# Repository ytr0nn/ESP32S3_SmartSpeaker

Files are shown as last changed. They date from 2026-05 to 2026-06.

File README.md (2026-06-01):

# ESP32S3_SmartSpeaker

An open-source, fully functional AI-powered smart speaker built around the **ESP32S3** microcontroller. The project features local wake-word detection, seamless integration with cloud-based AI models (OpenAI & Google Gemini), and dynamic visual feedback using a round LCD display and an addressable LED ring.

## Features

* **Local Wake Word Detection:** Uses the ESPSR framework to recognize the wake word locally, ensuring low latency.
* **Cloud AI Pipeline:** * **STT:** OpenAI Whisper API.
  * **LLM :** Google Gemini 3.5 Flash API for fast and smart responses.
  * **TTS :** OpenAI TTS API.
* **High-Quality Audio:** Employs an I2S digital MEMS microphone for clear voice capture and an I2S DAC for crisp audio playback.
* **Rich User Interface:** * A GC9A01 round display powered by **LVGL** showing device states and real-time clock.
  * A WS2812B addressable LED ring providing smooth, color-coded animations.
* **RTOS Architecture:** Built on **FreeRTOS** using the native **ESP-IDF**.
* **Custom Enclosure:** Designed specifically for 3D printing to optimize acoustics and component mounting.

## 🛠️ Hardware Requirements

* **Development Board:** ESP32S3 DevKit (Must have **8MB PSRAM** for audio buffering and TLS handshake).
* **Microphone:** ICS43434.
* **DAC / Amplifier:** PCM5102 + D class compact Audio Amplifier.
* **Display:** GC9A01 240x240 Round LCD .
* **LED Ring:** WS2812B (32 LEDs).
* **Audio Switch:** CD4053BE Analog Multiplexer (for switching between ESP32 and Bluetooth audio sources).
* **Misc:** Capacitive touch buttons, 3D printed enclosure.

## 💻 Software & APIs

* **Framework:** ESP-IDF v5.3+.
* **Libraries:** LVGL , ESP-SR , cJSON.
* **API Keys Required:**
  * OpenAI API Key Whisper & TTS
  * Google Gemini API Key

## ⚙️ Architecture & Flow

1. **Idle:** The device syncs time via SNTP. The display shows a blue pulsating orb and the LED ring "breathes".
2. **Wake Word:** The `ICS43434` mic feeds data to the `ESPSR` engine. Upon detecting wake word, the UI turns yellow.
3. **Recording:** Voice is recorded into the ESP32's PSRAM. VAD automatically stops recording when silence is detected.
4. **Processing (White UI):** The audio is encapsulated with a WAV header and sent to **OpenAI Whisper**. The recognized text is forwarded to **LLM**.
5. **Playback (Green UI/Rainbow LED):** The text response is sent to **OpenAI TTS**, and the resulting audio stream is played back via the `PCM5102` DAC.

## 🚀 Installation & Setup
```bash
1. Clone the Repository

git clone [https://github.com/ytr0nn/ESP32S3_SmartSpeaker.git](https://github.com/ytr0nn/ESP32S3_SmartSpeaker.git)
cd ESP32S3_SmartSpeaker

2. Configure API Keys and Wi-Fi

Open main/network_api.h and main/ai_agent.h or your config files and insert your credentials

3. ESP-IDF Menuconfig (CRITICAL SETTINGS)

Because AI APIs require large SSL certificates, you must configure mbedTLS to use PSRAM. Run:
Bash

idf.py menuconfig

Apply the following settings:

    ESP-TLS: Enable Use global CA store and Use PSRAM for SSL session.

    mbedTLS: Set Memory allocation strategy to Allocate SSL/TLS memory into PSRAM.

    ESP System Settings: Enable Allow external memory as a heap pool.

    Component config -> ESP Speech Recognition: Ensure your partition table matches the model size.

4. Build and Flash
Bash

idf.py build
idf.py -p (YOUR PORT) flash monitor

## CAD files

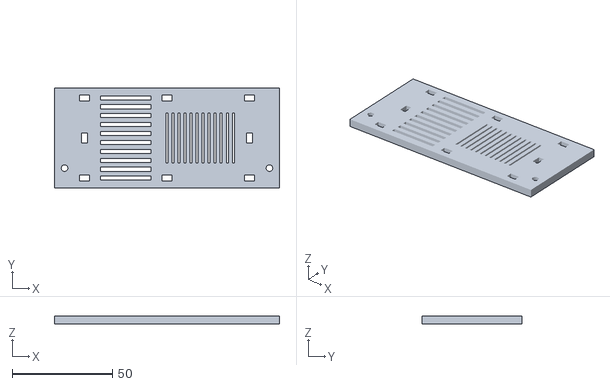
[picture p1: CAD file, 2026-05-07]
ESP32_S3_Smart_Speaker/3D files/Board Holder.stl
112.0 x 50.0 x 4.00

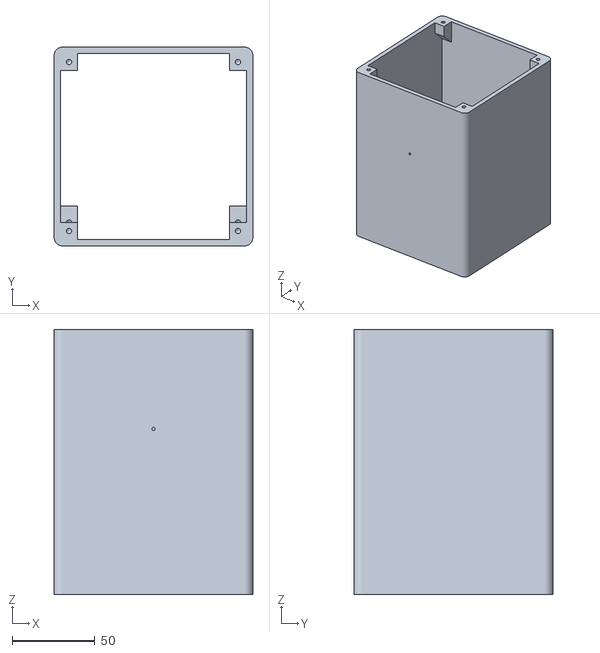
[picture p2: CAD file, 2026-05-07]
ESP32_S3_Smart_Speaker/3D files/CASE.stl
120.0 x 120.0 x 160.0

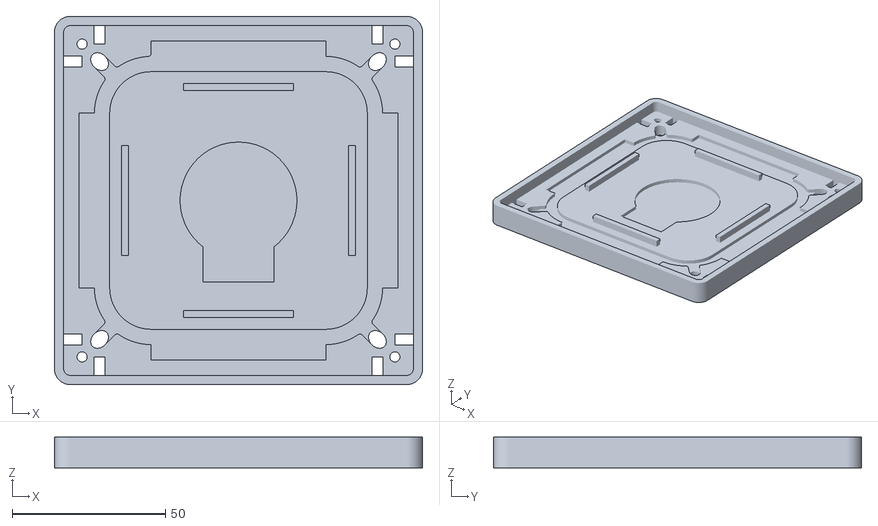
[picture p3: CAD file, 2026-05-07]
ESP32_S3_Smart_Speaker/3D files/Display Module.stl
120.0 x 120.0 x 10.0

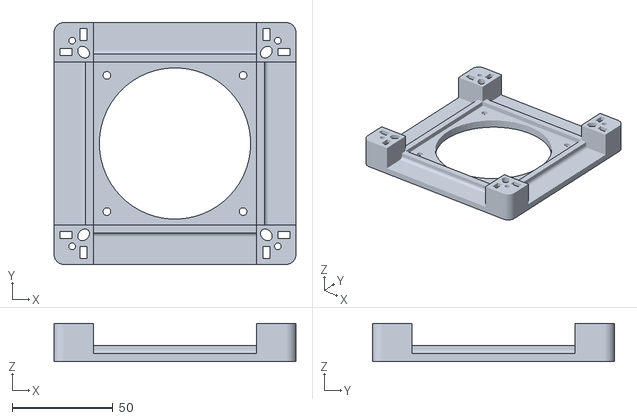
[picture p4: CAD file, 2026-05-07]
ESP32_S3_Smart_Speaker/3D files/Middle Frame.stl
120.0 x 120.0 x 19.0

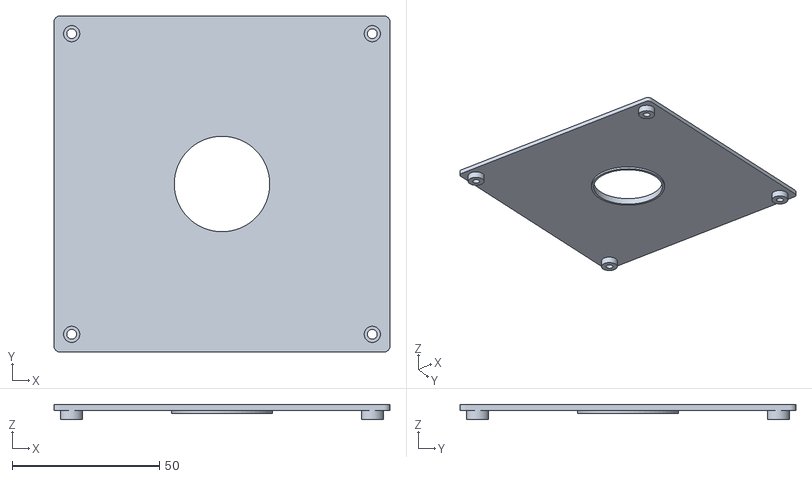
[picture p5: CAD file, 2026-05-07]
ESP32_S3_Smart_Speaker/3D files/Top lid.stl
114.0 x 114.0 x 5.00

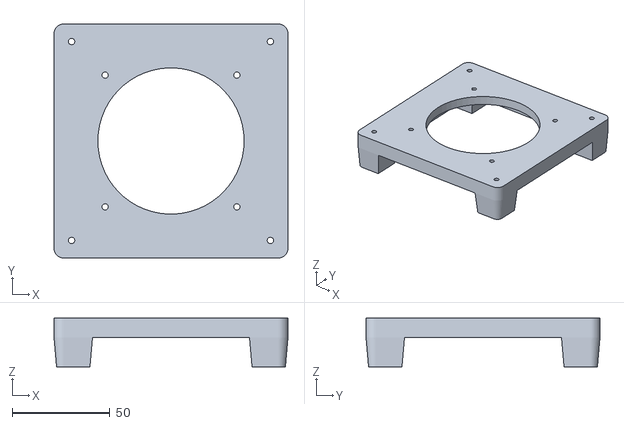
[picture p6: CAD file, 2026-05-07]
ESP32_S3_Smart_Speaker/3D files/LEGS.stl
120.0 x 120.0 x 25.0

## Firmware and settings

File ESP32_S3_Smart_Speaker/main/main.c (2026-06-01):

#include <stdio.h>
#include "esp_log.h"
#include "nvs_flash.h"
#include "esp_event.h"
#include "sys_manager.h"

static const char *TAG = "MAIN";

void app_main(void)
{
    ESP_LOGI(TAG, "Starting Smart AI Speaker Initialization YURII OSYPENKO");
    ESP_LOGI(TAG, "Free heap: %" PRIu32 " bytes", esp_get_free_heap_size());

    // 1. NVS 
    // 
    esp_err_t ret = nvs_flash_init();
    if (ret == ESP_ERR_NVS_NO_FREE_PAGES || ret == ESP_ERR_NVS_NEW_VERSION_FOUND) {
        ESP_LOGW(TAG, "NVS flash error");
        ESP_ERROR_CHECK(nvs_flash_erase());
        ret = nvs_flash_init();
    }
    ESP_ERROR_CHECK(ret);

    // 2. (ESP Event Loop)
    // 
    ESP_ERROR_CHECK(esp_event_loop_create_default());

    // 3.maneger
    // 
    // 
    sys_manager_init();

    ESP_LOGI(TAG, "Initialization complete. System Manager is running.");
    
}

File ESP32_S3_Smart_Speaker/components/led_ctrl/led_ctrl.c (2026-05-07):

#include "led_ctrl.h"
#include "esp_log.h"
#include "esp_err.h"
#include "freertos/FreeRTOS.h"
#include "freertos/task.h"
#include "led_strip.h"
#include "sys_manager.h"
#include <math.h>

static const char *TAG = "LED_CTRL";

// --- Hardware Configuration ---
#define LED_STRIP_BLINK_GPIO  48
#define LED_STRIP_LED_NUMBERS 32
#define LED_FRAME_RATE_MS     30  // ~33 FPS for smooth animations

static led_strip_handle_t led_strip;
static sys_state_t current_state = STATE_IDLE;

// ==============================================================================
// System Event Handler
// ==============================================================================
static void sys_event_handler(void* arg, esp_event_base_t event_base, int32_t event_id, void* event_data) {
    if (event_base == SYS_EVENT_BASE && event_id == SYS_EVENT_STATE_CHANGED) {
        if (event_data) {
            sys_state_t new_state = *(sys_state_t*)event_data;
            if (current_state != new_state) {
                ESP_LOGI(TAG, "LED state transitioning to: %d", new_state);
                current_state = new_state;
            }
        }
    }
}

// ==============================================================================
// Animation Patterns
// ==============================================================================

// Helper to convert HSV to RGB for smoother color transitions
static void hsv2rgb(uint32_t h, uint32_t s, uint32_t v, uint32_t *r, uint32_t *g, uint32_t *b) {
    h %= 360; 
    uint32_t rgb_max = v * 2.55f;
    uint32_t rgb_min = rgb_max * (100 - s) / 100.0f;
    uint32_t i = h / 60;
    uint32_t diff = h % 60;
    uint32_t rgb_adj = (rgb_max - rgb_min) * diff / 60;

    switch (i) {
        case 0: *r = rgb_max; *g = rgb_min + rgb_adj; *b = rgb_min; break;
        case 1: *r = rgb_max - rgb_adj; *g = rgb_max; *b = rgb_min; break;
        case 2: *r = rgb_min; *g = rgb_max; *b = rgb_min + rgb_adj; break;
        case 3: *r = rgb_min; *g = rgb_max - rgb_adj; *b = rgb_max; break;
        case 4: *r = rgb_min + rgb_adj; *g = rgb_min; *b = rgb_max; break;
        default: *r = rgb_max; *g = rgb_min; *b = rgb_max - rgb_adj; break;
    }
}

static void led_animation_task(void *pvParameters) {
    ESP_LOGI(TAG, "LED Animation Task started on Core %d", xPortGetCoreID());
    
    uint32_t tick = 0;
    uint32_t r, g, b;

    while (1) {
        led_strip_clear(led_strip);

        switch (current_state) {
            case STATE_WIFI_SETUP: {
    // slow blue for Wi-Fi setup
                float pulse = (sin((float)tick * 0.05f) + 1.0f) / 2.0f;
                uint8_t brightness = (uint8_t)(10 + pulse * 100);
                for (int i = 0; i < LED_STRIP_LED_NUMBERS; i++) {
                led_strip_set_pixel(led_strip, i, 0, 0, brightness); // Синий
                }
                break;
}
            case STATE_IDLE: {
                // Breathing effect (Cyan color)
                // Sine wave
                float breathe = (sin((float)tick * 0.05f) + 1.0f) / 2.0f; 
                uint8_t brightness = (uint8_t)(5 + (breathe * 35));
                for (int i = 0; i < LED_STRIP_LED_NUMBERS; i++) {
                    led_strip_set_pixel(led_strip, i, 0, brightness, brightness); // Cyan
                }
                break;
            }

            case STATE_LISTENING: {
                // Rotating Ring effectreen
                // Creates a comet tail that spins around the 32 LED
                int head_pos = (tick / 2) % LED_STRIP_LED_NUMBERS;
                for (int i = 0; i < 8; i++) { // Tail length = 8
                    int pixel = (head_pos - i + LED_STRIP_LED_NUMBERS) % LED_STRIP_LED_NUMBERS;
                    uint8_t fade = 255 - (i * 30); // Fade out tail
                    led_strip_set_pixel(led_strip, pixel, 0, fade, 0); // Pure Green
                }
                break;
            }

            case STATE_THINKING: {
                // Pulsing effect Purple
                // Simulates processing data with API
                for (int i = 0; i < LED_STRIP_LED_NUMBERS; i++) {
                    float pulse = (sin((float)(tick + i * 2) * 0.2f) + 1.0f) / 2.0f;
                    uint8_t intensity = (uint8_t)(20 + pulse * 100);
                    led_strip_set_pixel(led_strip, i, intensity / 2, 0, intensity); // Purple
                }
                break;
            }

            case STATE_SPEAKING: {
                // random sparkles with rainbow colors
                // 
                uint32_t hue = (tick * 5) % 360;
                for (int i = 0; i < LED_STRIP_LED_NUMBERS; i++) {
                    // Two moving waves colliding
                    float wave = sin((float)i * 0.5f + (float)tick * 0.2f) + sin((float)i * 0.5f - (float)tick * 0.15f);
                    if (wave > 0.5f) {
                        hsv2rgb(hue + (i * 10), 100, 100, &r, &g, &b);
                        led_strip_set_pixel(led_strip, i, r, g, b);
                    }
                }
                break;
            }

            case STATE_ERROR: {
                // Fast Flashing Red
                if ((tick / 10) % 2 == 0) {
                    for (int i = 0; i < LED_STRIP_LED_NUMBERS; i++) {
                        led_strip_set_pixel(led_strip, i, 150, 0, 0); // Red
                    }
                }
                break;
            }

            default:
                break;
        }

        // Push pixels to the hardware
        led_strip_refresh(led_strip);

        // Frame delay and tick increment
        vTaskDelay(pdMS_TO_TICKS(LED_FRAME_RATE_MS));
        tick++;
    }
}

// ==============================================================================
// Public API
// ==============================================================================
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

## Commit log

2026-05-06 Added 3D files of speaker V1.0
    [Board Holder.stl, CASE.stl, Display Module.stl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]
2026-05-06 Implement initial setup for Smart Speaker features including audio, network, and UI components
    [partitions.csv]
2026-05-06 Add audio processing and wake word detection features
    - Implement audio I2S initialization and RX task for audio data handling
    - Create wake word detection engine with associated tasks
    - Update CMakeLists and header files to include new components
    - Modify dependencies and partition sizes for improved functionality
    [partitions.csv]
2026-05-07 Project restructurisation. V1.1
    [partitions.csv]
2026-06-01 Enhance README with project details and setup instructions
    Added detailed project description, features, hardware requirements, software dependencies, architecture flow, and installation instructions.
